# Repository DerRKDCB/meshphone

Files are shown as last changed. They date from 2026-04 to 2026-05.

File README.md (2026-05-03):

# Meshphone

A standalone dual-node Meshtastic/MeshCore device built into a Samsung Galaxy A5 form factor.

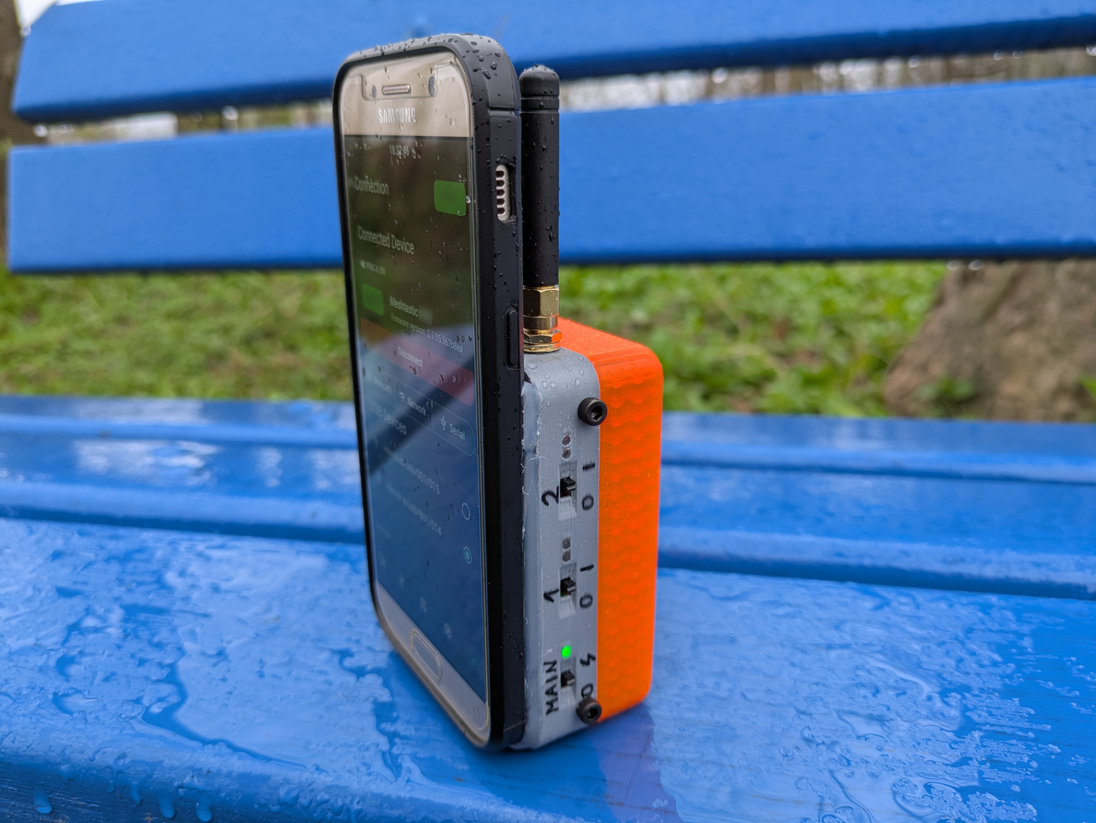
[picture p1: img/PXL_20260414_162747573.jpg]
Meshphone


## Overview

Meshphone is a custom dual-node Meshtastic device featuring:
- Two RAK4630 modules for simultaneous operation with different presets/protocols
- Integrated USB hub for clean connectivity
- 8000mAh 4P 18650 LiPo battery (~48h runtime)
- Samsung Galaxy A5 chassis (€20 eBay find)

## Why Build This?

Off-the-shelf standalone devices like the T-Deck lack the full feature set available in Meshtastic/MeshCore. By making it a dual-node device, I can run two different configurations simultaneously. The nodes connect through a USB hub IC - a cleaner solution than Bluetooth coupling with potential radio interference over short distances.

## Design

### Chassis
The Galaxy A5's internal battery was removed and replaced with external power from the PCB via cables. This allows complete disconnection via switch and increased battery capacity. The phone sits in a cheap TPU case, with 3D printed PLA housing for the nodes and batteries, secured with hot glue.

### Core Components

**RAK4630 Modules** - Chosen for:
- Low power consumption
- Minimal peripheral components
- Integrated USB

Reference designs: RAK4631 and RAK19003 modules.

> **Note:** The RAK USB port requires 5V on VBUS to initialize - learned this during integration and had to bodge it. Fixed in the PCB design.

**Status LEDs (7 total):**
- Charging indicator
- Fully charged indicator
- ON/3.3V OK
- 2x Status Node 1
- 2x Status Node 2

Light channels made from clear PETG filament - works awesome!

**Battery Management:**
- TP4056 + DW01 for charging and protection (classic LiPo charging circuit)
- USB-C charging port on bottom (power only, no data)

**USB Hub - CH334P:**
- First USB project for me
- Chosen for cost and simple reference schematic
- Upstream port centered on PCB
- Phone connects via right-angle USB-C cable
- Pluggable design allows connecting other devices for firmware updates, etc.
- Differential pair routing where possible - USB worked first try!

**3.3V Supply:** TI TPS62203DBVT low-power buck converter

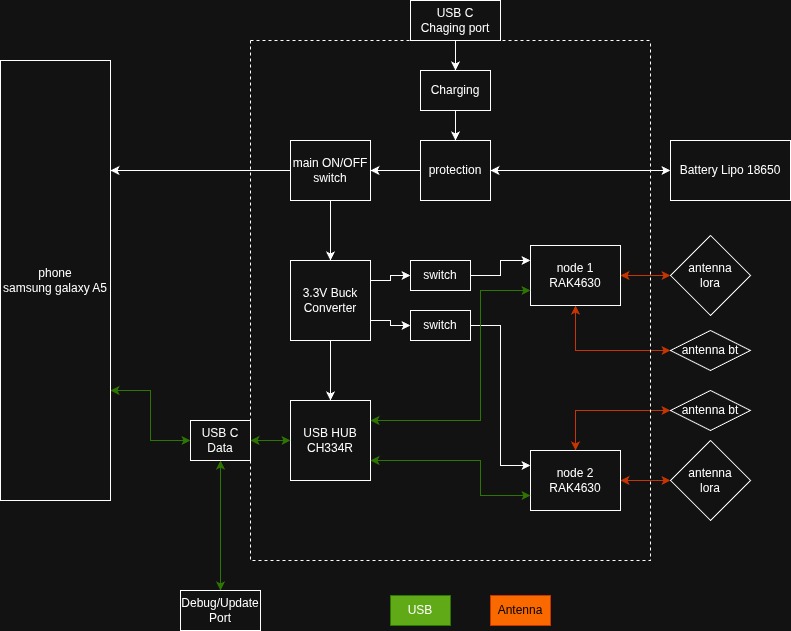
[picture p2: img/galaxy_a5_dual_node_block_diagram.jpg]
Block Diagram

[Schematic PDF](kicad/galaxy_A5_dual_node/galaxy_A5_dual_node.pdf)

### Fixes & Issues

**Bodged during build:**
- USB port didn't activate - forgot 5.1k resistors on CC1/CC2 (fixed in PCB)
- RAK VBUS 5V supply (fixed in PCB)
- Bootloader flash via SWD required for USB drive mode (double-click reset) - used [WisCore RAK4631 Bootloader](https://github.com/oltaco/WisCore_RAK4631_Bootloader)

**Remaining issue:**
When switching on either node, the hub disconnects and reconnects completely, making it impossible to differentiate which node is which USB device. Not sure why this happens, but it's manageable.

## Documentation

- [Component references and links](notes.md)
- [KiCad PCB files](kicad/galaxy_A5_dual_node/)
- [FreeCAD 3D models](freecad/)

## Final Thoughts

This project was an awesome learning experience and I love the result. For future versions I'd do some things differently - most likely keeping the battery in the phone and supplying the whole PCB from the phone's USB port.

## Images

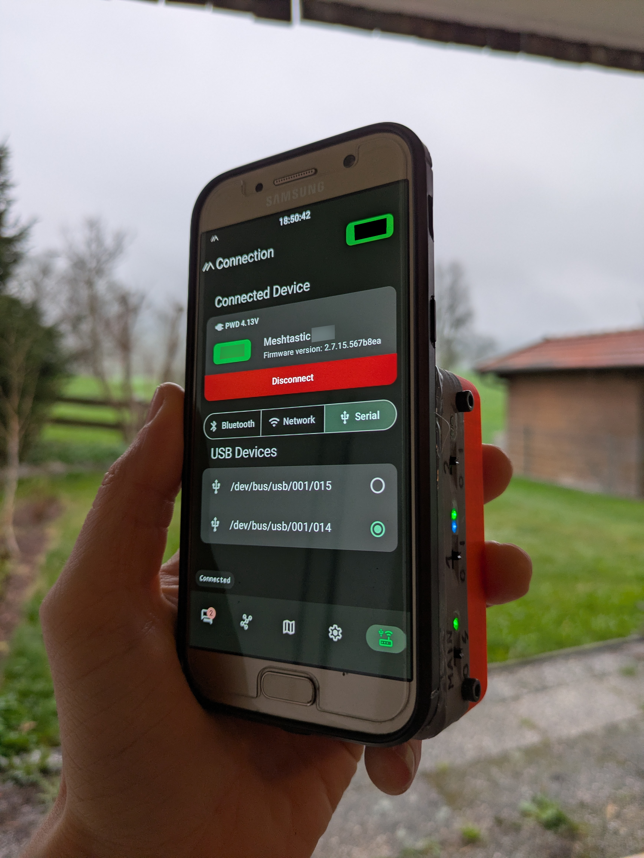
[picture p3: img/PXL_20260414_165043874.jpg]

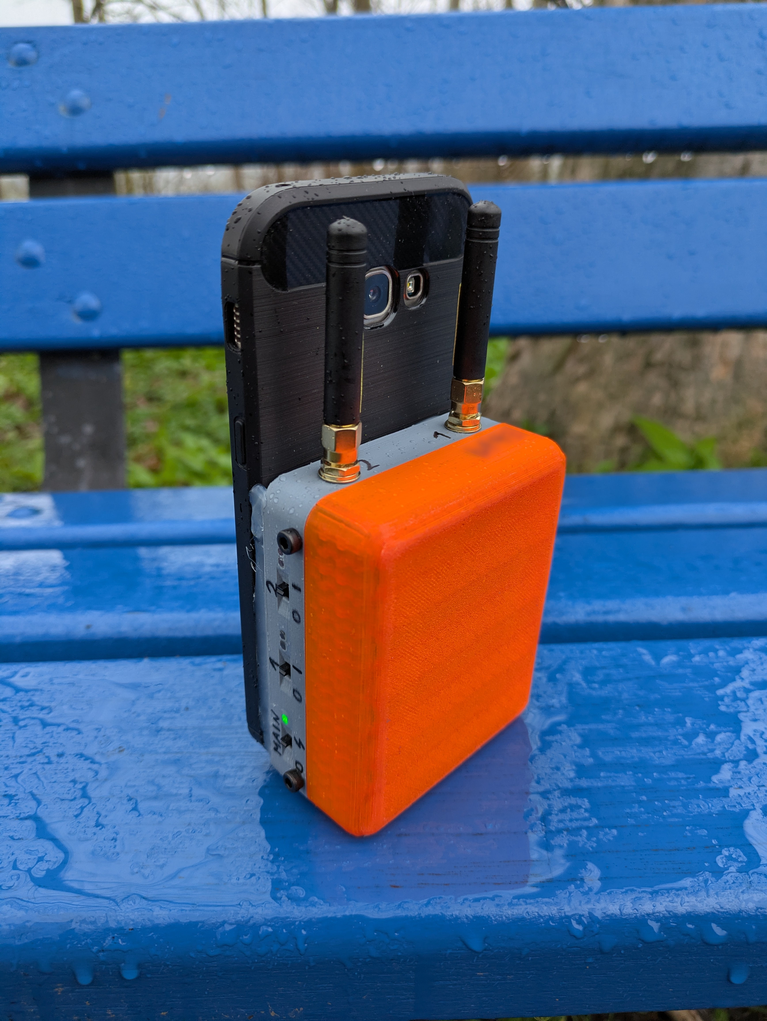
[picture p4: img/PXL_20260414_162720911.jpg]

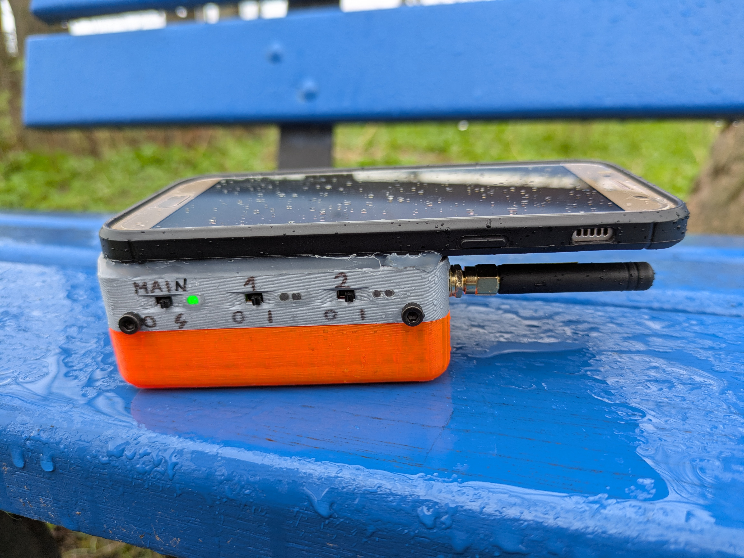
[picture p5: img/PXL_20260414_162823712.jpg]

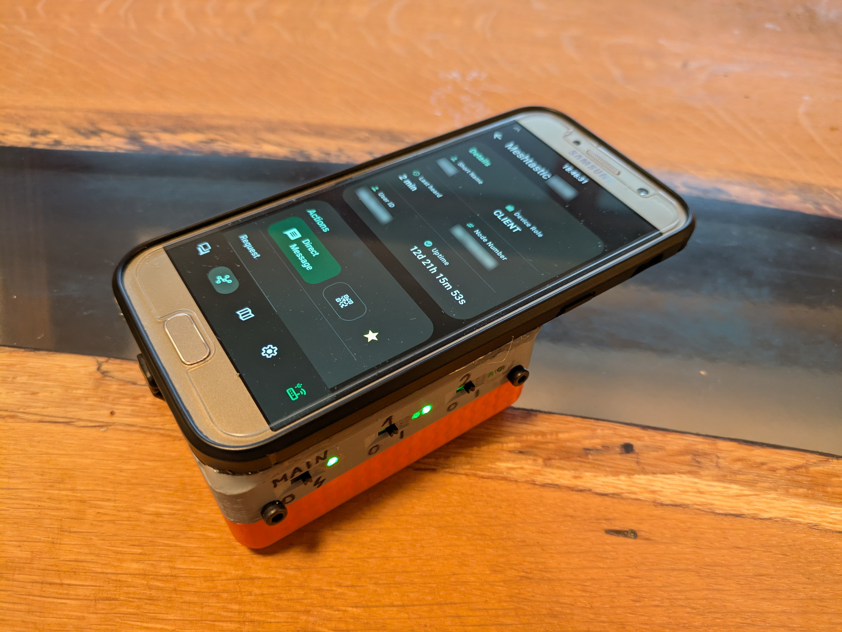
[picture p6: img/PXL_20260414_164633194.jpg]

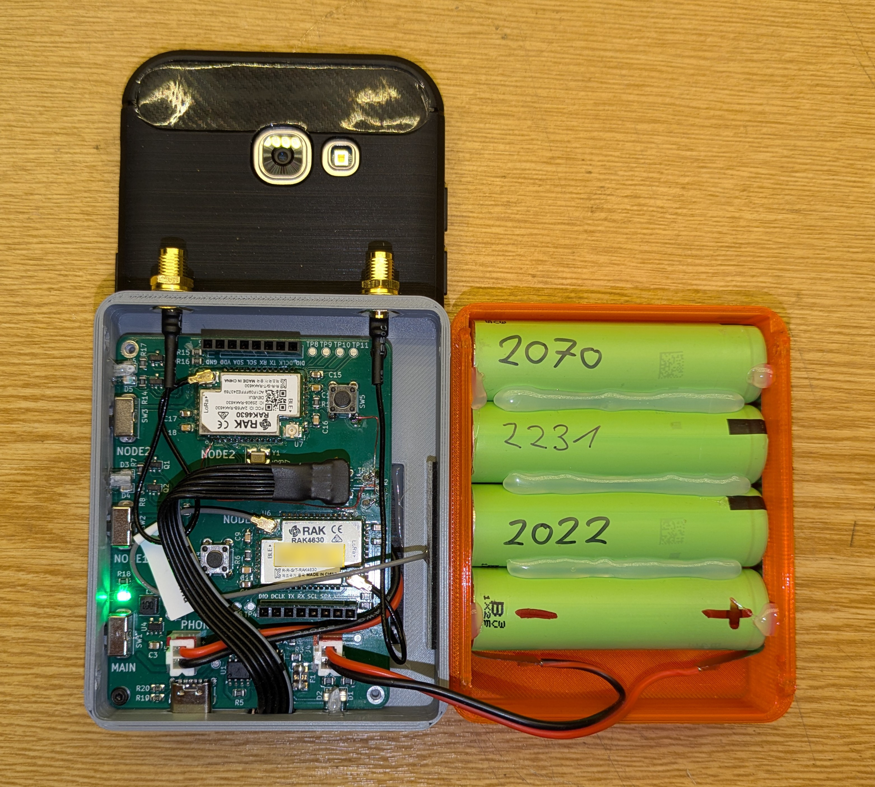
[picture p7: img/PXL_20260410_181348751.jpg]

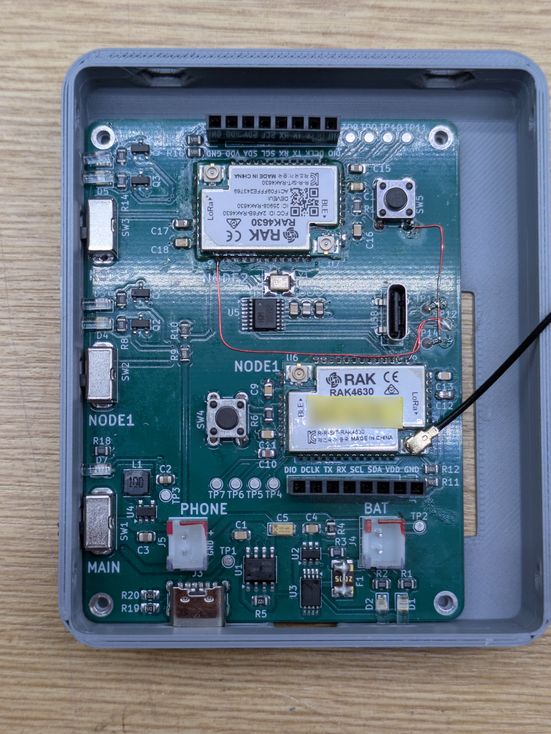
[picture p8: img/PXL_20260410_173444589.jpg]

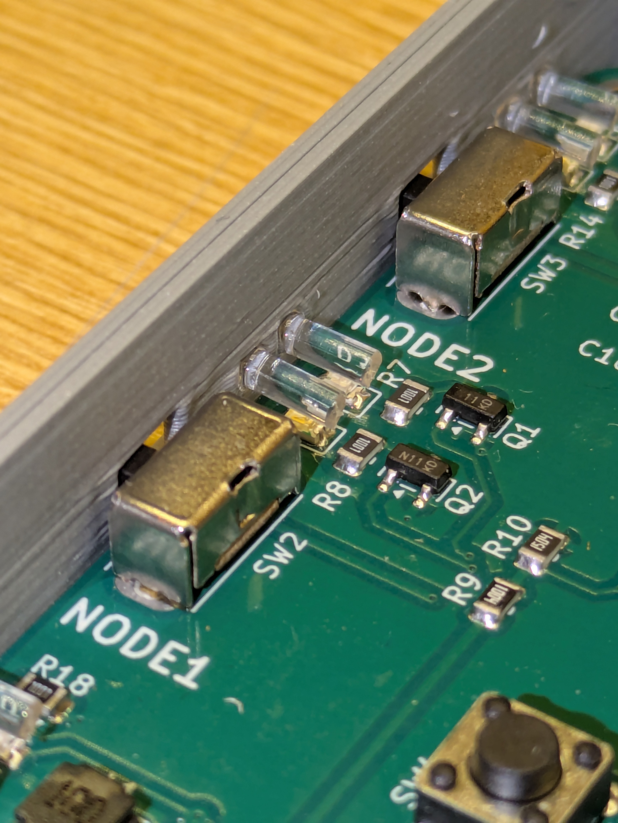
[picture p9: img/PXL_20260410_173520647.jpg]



by DerRKDCB

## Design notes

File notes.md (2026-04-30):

galaxy_a5_dual_node_block_diagram

# RAK4630

https://de.aliexpress.com/item/1005004148412772.html

https://docs.rakwireless.com/product-categories/wisduo/rak4630-module/datasheet/

minimal Hardware Setup
https://docs.rakwireless.com/product-categories/wisduo/rak4630-module/quickstart/#hardware-setup

# RAK4631

overview
https://docs.rakwireless.com/product-categories/wisblock/rak4631/overview/

datasheet
https://docs.rakwireless.com/product-categories/wisblock/rak4631/datasheet/

# RAK19003

https://docs.rakwireless.com/product-categories/wisblock/rak19003/datasheet/

TPS62840YBG

# USB Hub

CH334P

lcsc
https://www.lcsc.com/product-detail/C5373042.html?s_z=n_usb%2520hub%2520wch

datasheet
https://cdn-learn.adafruit.com/assets/assets/000/131/435/original/CH334DS1.PDF?1721660148

VDD33 and V5 can be supplied with 3.3V

differential pair tutorial 
https://www.pcbway.com/blog/PCB_Design_Tutorial/KiCad____How_to_make_differential_pair_traces.html

# LiPo

## Charging + Protection

Reference TP4056


datasheet https://datasheet.lcsc.com/lcsc/1809261820_TOPPOWER-Nanjing-Extension-Microelectronics-TP4056-42-ESOP8_C16581.pdf

R3
rprog

# 3.3V Buck

TI TPS62203DBVT
fixed 3.3V

lcsc
https://www.lcsc.com/product-detail/C2070733.html?s_z=n_TPS62203DBVT

datasheet
https://www.lcsc.com/datasheet/C2070733.pdf

# USB C connector

## Vertical Data
lcsc
C7450621
https://www.lcsc.com/product-detail/C7450621.html

# Switches
lcsc
https://www.lcsc.com/product-detail/C393937.html

footprint:
SW_Slide_SPDT_Angled_CK_OS102011MA1Q

# TODO

- OK power led 3.3V/VDD
- OK status leds RAK
- OK mounting holes
- OK testpoints- SDIO, RXTX Breakout
- OK reset button

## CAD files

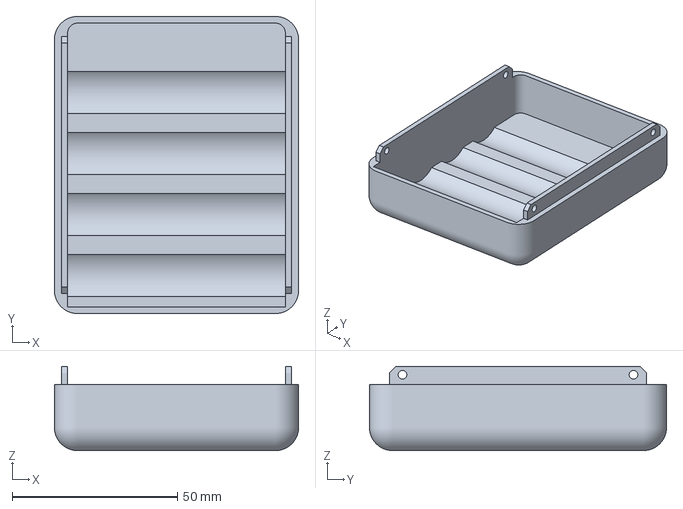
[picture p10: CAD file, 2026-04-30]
freecad/3mf/housing-battery_lid.3mf
74.0 x 90.0 x 25.5 mm

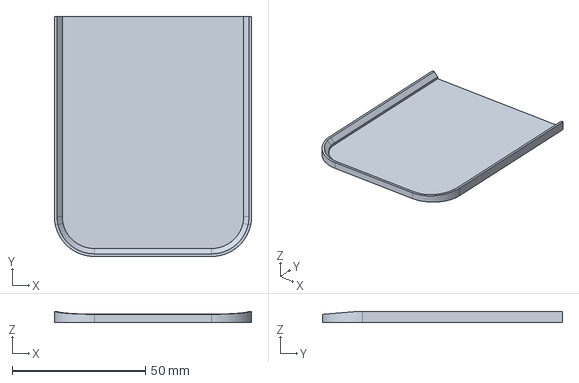
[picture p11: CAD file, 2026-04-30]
freecad/phone_case_size_test.FCStd
74.0 x 90.0 x 4.00 mm

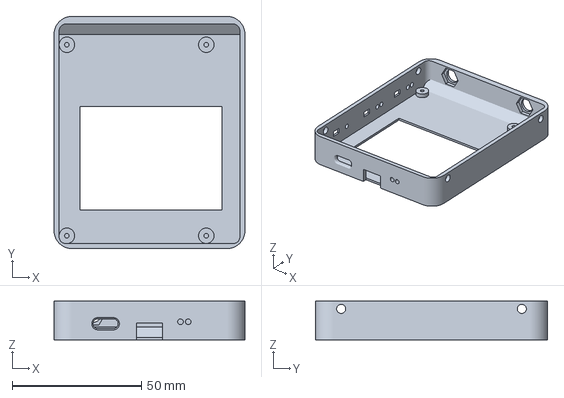
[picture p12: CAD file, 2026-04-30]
freecad/3mf/housing-pcb_housing.3mf
74.0 x 90.0 x 15.0 mm

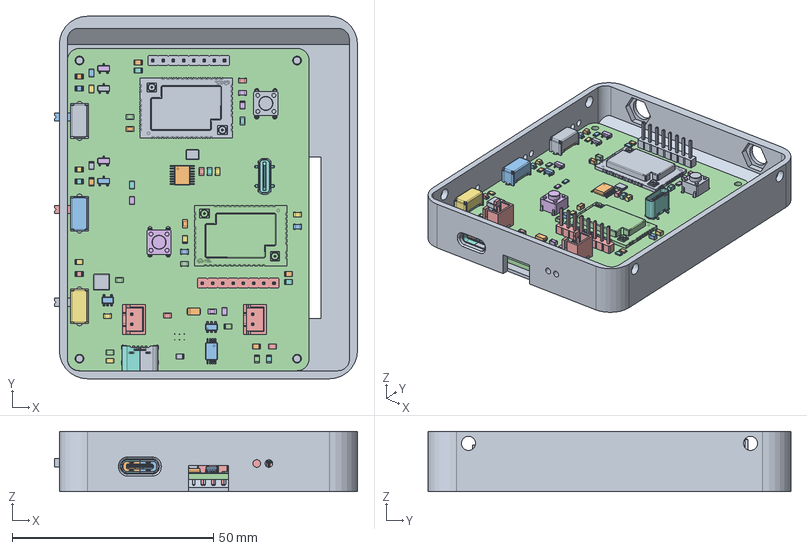
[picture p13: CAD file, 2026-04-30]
freecad/back_housing.FCStd
75.2 x 90.0 x 15.0 mm
LED_0805_2012Metric
C_0805_2012Metric
R_0805_2012Metric
LED_0805_2012Metric001
SOT-23
C_0805_2012Metric001
R_0805_2012Metric001
SW_Slide_SPDT_Angled_CK_OS102011MA1Q
SW_Slide_SPDT_Angled_CK_OS102011MA1Q001
SW_Slide_SPDT_Angled_CK_OS102011MA1Q002
SW_Slide_SPDT_Angled_CK_OS102011MA1Q003
SW_Slide_SPDT_Angled_CK_OS102011MA1Q004
SW_Slide_SPDT_Angled_CK_OS102011MA1Q005
SW_Slide_SPDT_Angled_CK_OS102011MA1Q007
SW_Slide_SPDT_Angled_CK_OS102011MA1Q008
SW_Slide_SPDT_Angled_CK_OS102011MA1Q009
SW_Slide_SPDT_Angled_CK_OS102011MA1Q010
SW_Slide_SPDT_Angled_CK_OS102011MA1Q011
SW_Slide_SPDT_Angled_CK_OS102011MA1Q012
C_0805_2012Metric002
C_0805_2012Metric003
R_0805_2012Metric002
C_0805_2012Metric004
L_APV_ANR4018
R_0805_2012Metric003
SOT-001
C_0805_2012Metric005
JST_XH_B2B-XH-A_1x02_P2.50mm_Vertical
SW_PUSH_6mm_H5mm
R_0805_2012Metric004
LED_0805_2012Metric002
PinHeader_1x08_P2.54mm_Vertical
R_0805_2012Metric005
SOT-23-5
R_0805_2012Metric006
R_0805_2012Metric007
R_0805_2012Metric008
R_0805_2012Metric009
R_0805_2012Metric010
R_0805_2012Metric011
USB_C_Receptacle_GCT_USB4125-xx-x_6P_TopMnt_Horizontal
USB_C_Receptacle_GCT_USB4125-xx-x_6P_TopMnt_Horizontal001
USB_C_Receptacle_GCT_USB4125-xx-x_6P_TopMnt_Horizontal002
USB_C_Receptacle_GCT_USB4125-xx-x_6P_TopMnt_Horizontal003
USB_C_Receptacle_GCT_USB4125-xx-x_6P_TopMnt_Horizontal004
USB_C_Receptacle_GCT_USB4125-xx-x_6P_TopMnt_Horizontal005
USB_C_Receptacle_GCT_USB4125-xx-x_6P_TopMnt_Horizontal006
USB_C_Receptacle_GCT_USB4125-xx-x_6P_TopMnt_Horizontal007
USB_C_Receptacle_GCT_USB4125-xx-x_6P_TopMnt_Horizontal008
USB_C_Receptacle_GCT_USB4125-xx-x_6P_TopMnt_Horizontal009
USB_C_Receptacle_GCT_USB4125-xx-x_6P_TopMnt_Horizontal010
USB_C_Receptacle_GCT_USB4125-xx-x_6P_TopMnt_Horizontal011
USB_C_Receptacle_GCT_USB4125-xx-x_6P_TopMnt_Horizontal012
USB_C_Receptacle_GCT_USB4125-xx-x_6P_TopMnt_Horizontal013
USB_C_Receptacle_GCT_USB4125-xx-x_6P_TopMnt_Horizontal014
USB_C_Receptacle_GCT_USB4125-xx-x_6P_TopMnt_Horizontal015
C_0805_2012Metric006
TSSOP-8_4.4x3mm_P0.65mm
COMM-SMD_44P-L23.0-W15.0-P1.20_RAK4630-8-SM-I
JST_XH_B2B-XH-A_1x02_P2.50mm_Vertical001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

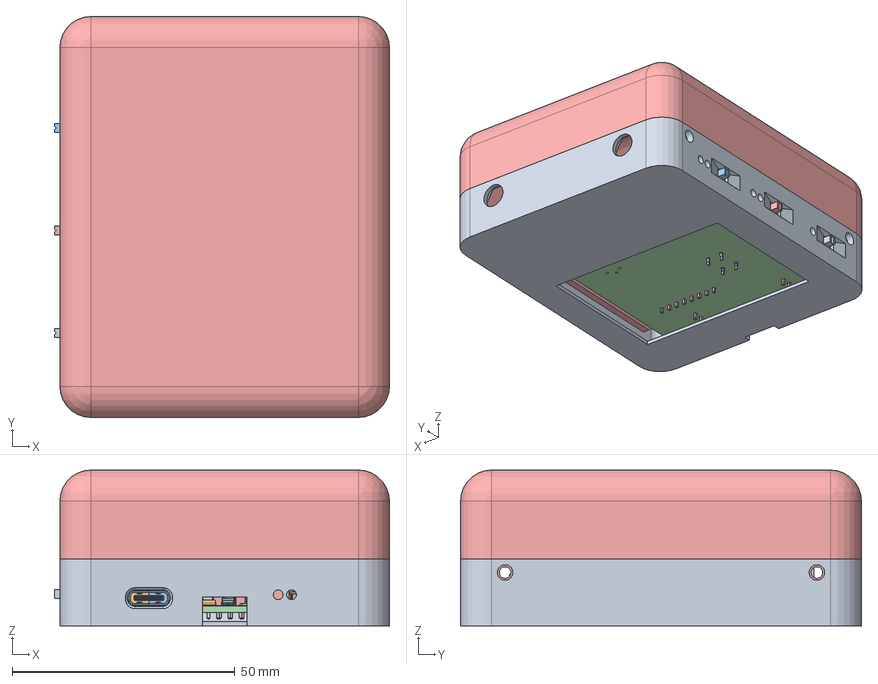
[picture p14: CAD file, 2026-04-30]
freecad/housing.FCStd
75.2 x 90.0 x 35.0 mm
pcb_housing
LED_0805_2012Metric
C_0805_2012Metric
R_0805_2012Metric
LED_0805_2012Metric001
SOT-23
C_0805_2012Metric001
R_0805_2012Metric001
SW_Slide_SPDT_Angled_CK_OS102011MA1Q
SW_Slide_SPDT_Angled_CK_OS102011MA1Q001
SW_Slide_SPDT_Angled_CK_OS102011MA1Q002
SW_Slide_SPDT_Angled_CK_OS102011MA1Q003
SW_Slide_SPDT_Angled_CK_OS102011MA1Q004
SW_Slide_SPDT_Angled_CK_OS102011MA1Q005
SW_Slide_SPDT_Angled_CK_OS102011MA1Q007
SW_Slide_SPDT_Angled_CK_OS102011MA1Q008
SW_Slide_SPDT_Angled_CK_OS102011MA1Q009
SW_Slide_SPDT_Angled_CK_OS102011MA1Q010
SW_Slide_SPDT_Angled_CK_OS102011MA1Q011
SW_Slide_SPDT_Angled_CK_OS102011MA1Q012
C_0805_2012Metric002
C_0805_2012Metric003
R_0805_2012Metric002
C_0805_2012Metric004
L_APV_ANR4018
R_0805_2012Metric003
SOT-001
C_0805_2012Metric005
JST_XH_B2B-XH-A_1x02_P2.50mm_Vertical
SW_PUSH_6mm_H5mm
R_0805_2012Metric004
LED_0805_2012Metric002
PinHeader_1x08_P2.54mm_Vertical
R_0805_2012Metric005
SOT-23-5
R_0805_2012Metric006
R_0805_2012Metric007
R_0805_2012Metric008
R_0805_2012Metric009
R_0805_2012Metric010
R_0805_2012Metric011
USB_C_Receptacle_GCT_USB4125-xx-x_6P_TopMnt_Horizontal
USB_C_Receptacle_GCT_USB4125-xx-x_6P_TopMnt_Horizontal001
USB_C_Receptacle_GCT_USB4125-xx-x_6P_TopMnt_Horizontal002
USB_C_Receptacle_GCT_USB4125-xx-x_6P_TopMnt_Horizontal003
USB_C_Receptacle_GCT_USB4125-xx-x_6P_TopMnt_Horizontal004
USB_C_Receptacle_GCT_USB4125-xx-x_6P_TopMnt_Horizontal005
USB_C_Receptacle_GCT_USB4125-xx-x_6P_TopMnt_Horizontal006
USB_C_Receptacle_GCT_USB4125-xx-x_6P_TopMnt_Horizontal007
USB_C_Receptacle_GCT_USB4125-xx-x_6P_TopMnt_Horizontal008
USB_C_Receptacle_GCT_USB4125-xx-x_6P_TopMnt_Horizontal009
USB_C_Receptacle_GCT_USB4125-xx-x_6P_TopMnt_Horizontal010
USB_C_Receptacle_GCT_USB4125-xx-x_6P_TopMnt_Horizontal011
USB_C_Receptacle_GCT_USB4125-xx-x_6P_TopMnt_Horizontal012
USB_C_Receptacle_GCT_USB4125-xx-x_6P_TopMnt_Horizontal013
USB_C_Receptacle_GCT_USB4125-xx-x_6P_TopMnt_Horizontal014
USB_C_Receptacle_GCT_USB4125-xx-x_6P_TopMnt_Horizontal015
C_0805_2012Metric006
TSSOP-8_4.4x3mm_P0.65mm
COMM-SMD_44P-L23.0-W15.0-P1.20_RAK4630-8-SM-I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

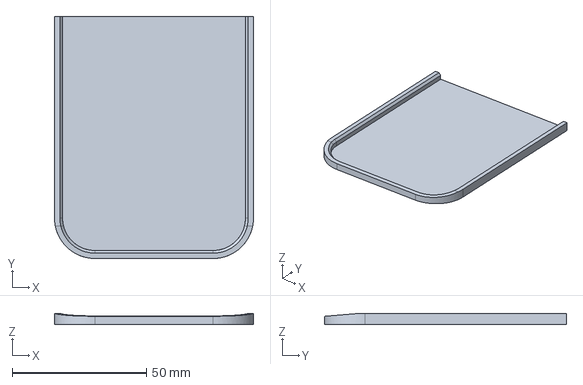
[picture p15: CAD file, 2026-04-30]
freecad/phone_case_size_test.sync-conflict-20260314-142446-KBQ5AQF.FCStd
74.0 x 90.0 x 4.00 mm

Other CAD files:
freecad/3mf/phone_case_size_test-Body.3mf
freecad/phone_case_size_test.sync-conflict-20260314-142535-KBQ5AQF.FCStd

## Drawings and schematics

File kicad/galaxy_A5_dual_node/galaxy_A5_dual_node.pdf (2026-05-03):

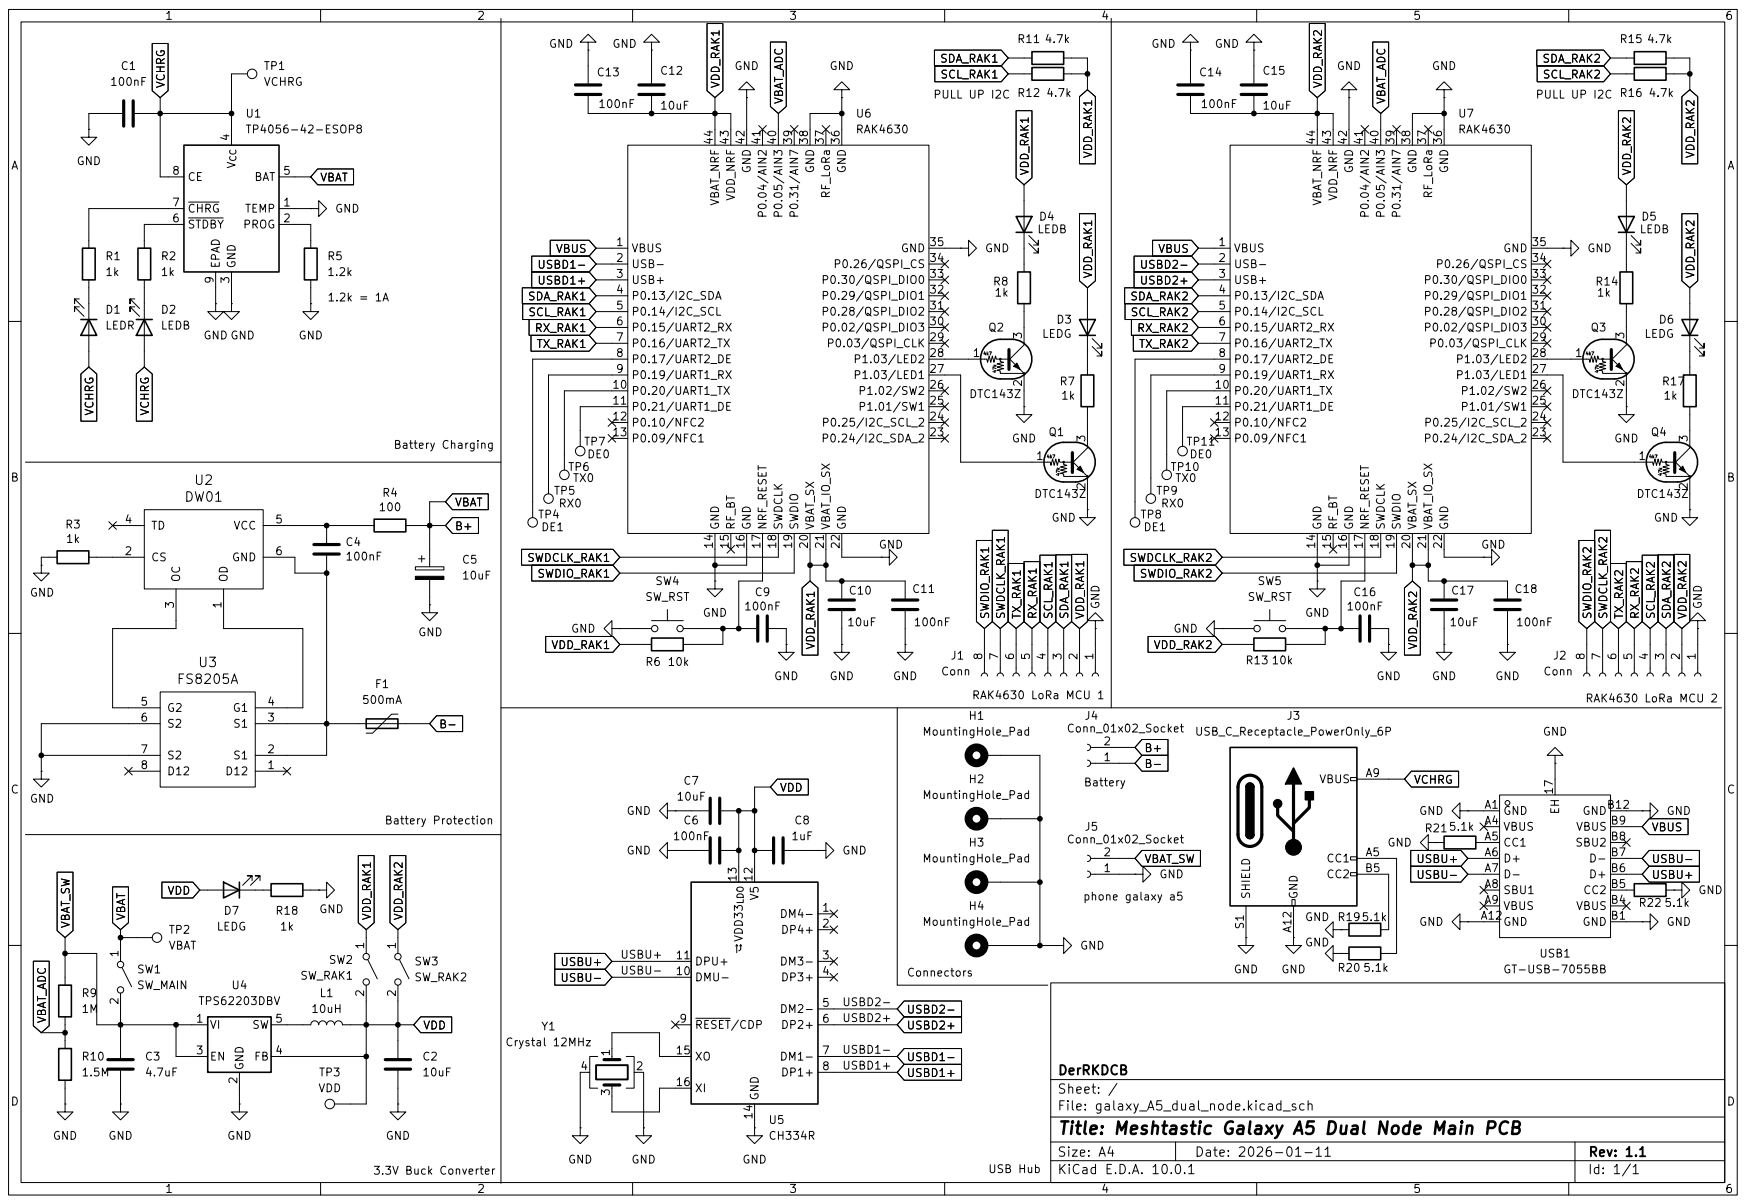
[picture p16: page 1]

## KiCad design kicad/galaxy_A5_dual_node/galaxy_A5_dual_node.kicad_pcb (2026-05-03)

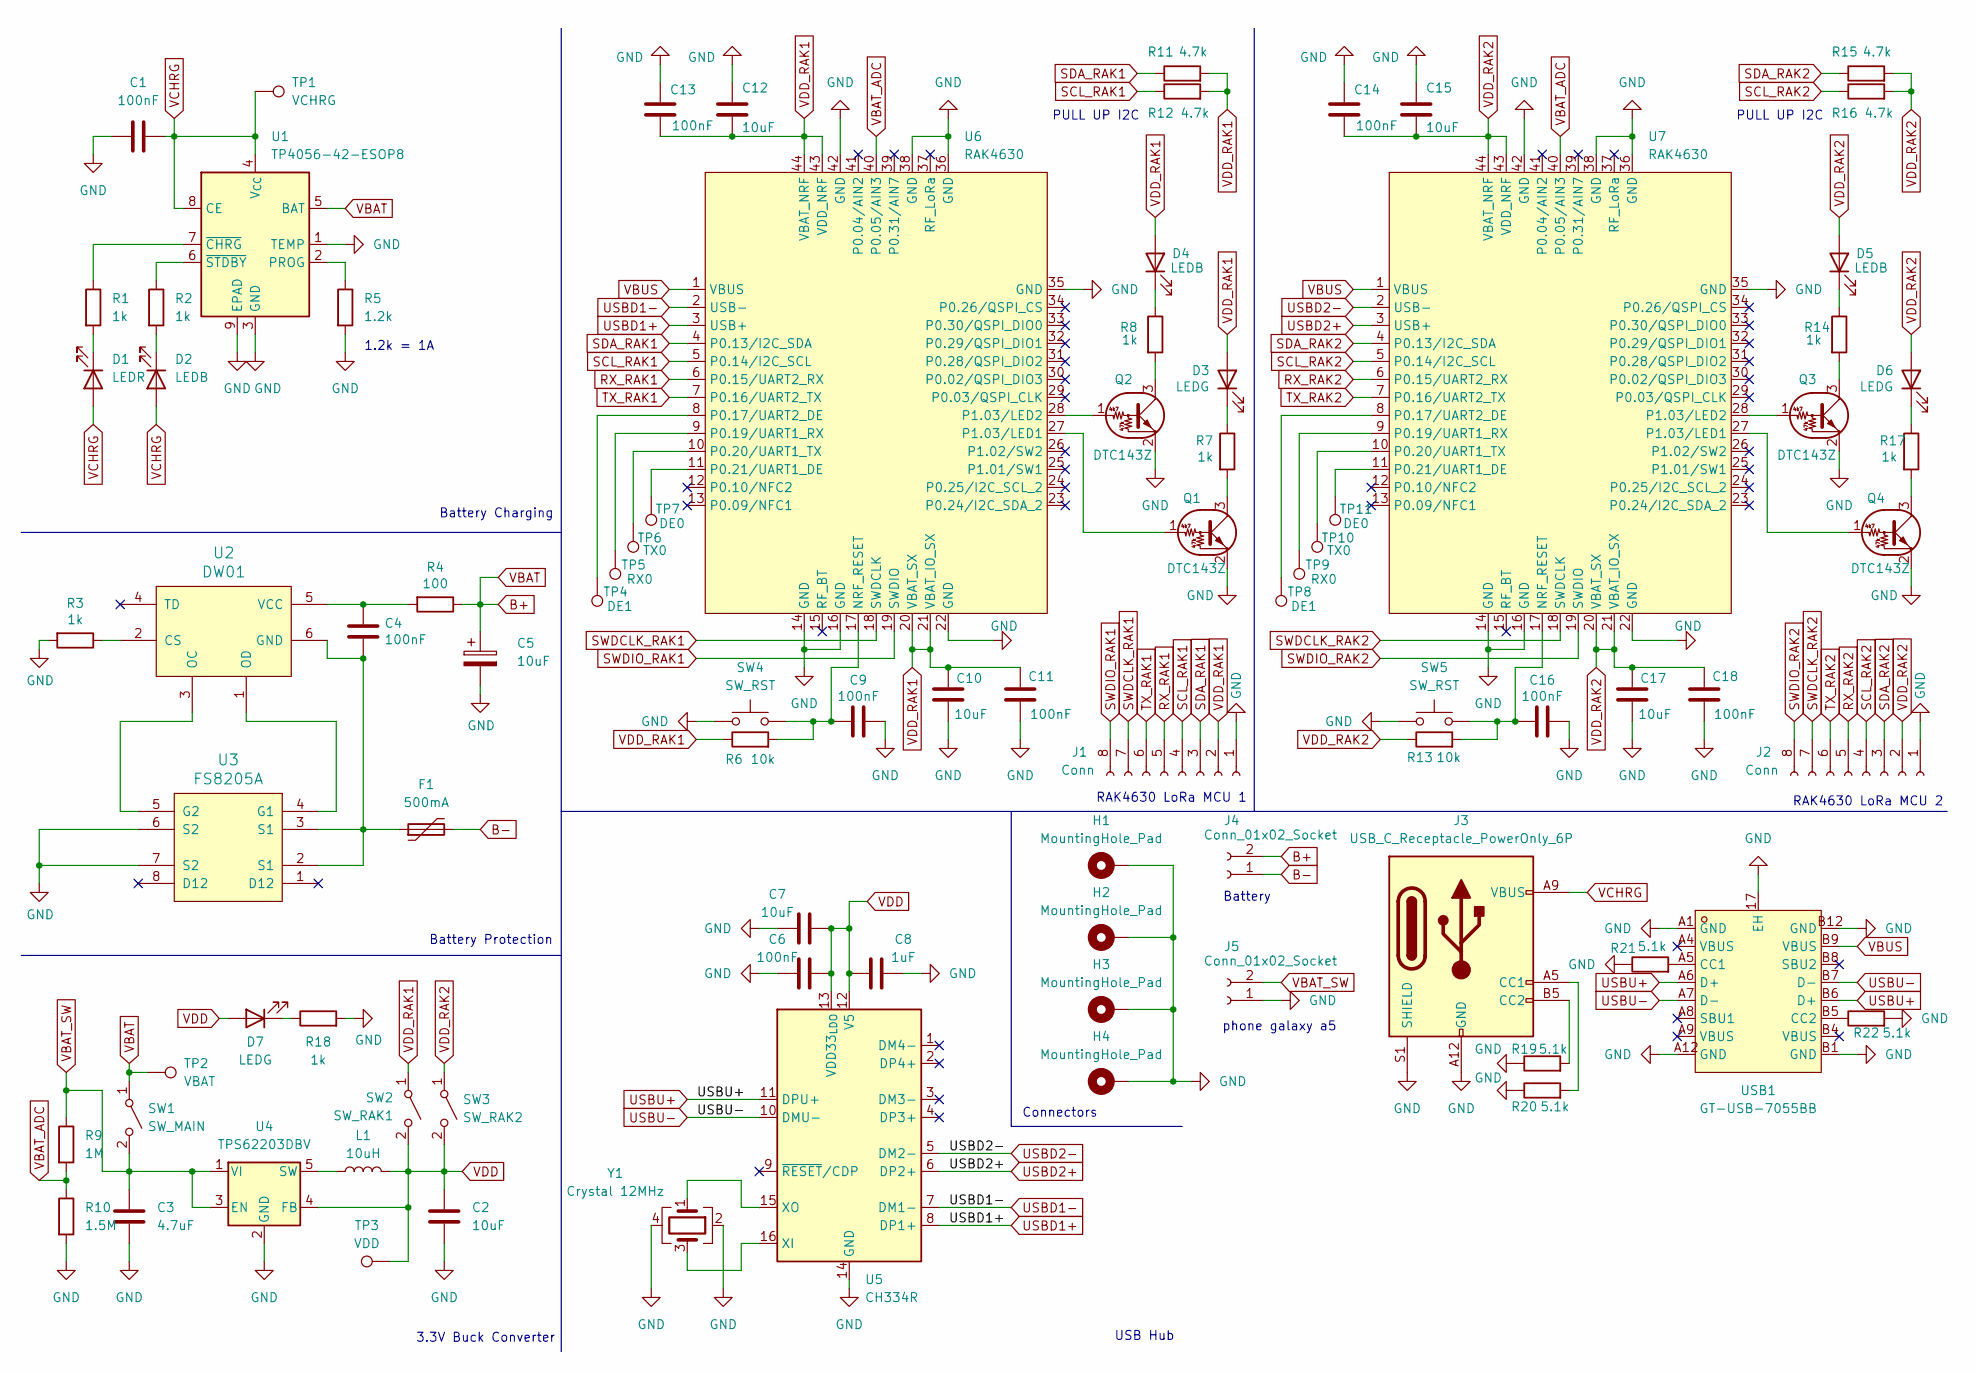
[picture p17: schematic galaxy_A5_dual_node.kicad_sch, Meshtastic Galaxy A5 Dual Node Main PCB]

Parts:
C1, C4, C6, C9, C11, C13, C14, C16, C18: 100nF; C_0805_2012Metric
C2, C7, C10, C12, C15, C17: 10uF; C_0805_2012Metric
C3: 4.7uF; C_0805_2012Metric
C5: 10uF; CP_EIA-3216-12_Kemet-S
C8: 1uF; C_0805_2012Metric
D1: LEDR; LED_0805_2012Metric
D2, D4, D5: LEDB; LED_0805_2012Metric
D3, D6, D7: LEDG; LED_0805_2012Metric
F1: 500mA; Fuse_1812_4532Metric_Pad1.30x3.40mm_HandSolder
H1, H2, H3, H4: MountingHole_Pad; MountingHole_2.2mm_M2_DIN965_Pad_TopBottom
J1, J2: Conn; PinHeader_1x08_P2.54mm_Vertical
J3: USB_C_Receptacle_PowerOnly_6P; USB_C_Receptacle_GCT_USB4125-xx-x_6P_TopMnt_Horizontal
J4, J5: Conn_01x02_Socket; JST_XH_B2B-XH-A_1x02_P2.50mm_Vertical
L1: 10uH; L_APV_ANR4018
Q1, Q2, Q3, Q4: DTC143Z; SOT-23
R1, R2, R3, R7, R8, R14, R17, R18: 1k; R_0805_2012Metric
R4: 100; R_0805_2012Metric
R5: 1.2k; R_0805_2012Metric
R6, R13: 10k; R_0805_2012Metric
R9: 1M; R_0805_2012Metric
R10: 1.5M; R_0805_2012Metric
R11, R12, R15, R16: 4.7k; R_0805_2012Metric
R19, R20, R21, R22: 5.1k; R_0805_2012Metric
SW1: SW_MAIN; SW_Slide_SPDT_Angled_CK_OS102011MA1Q
SW2: SW_RAK1; SW_Slide_SPDT_Angled_CK_OS102011MA1Q
SW3: SW_RAK2; SW_Slide_SPDT_Angled_CK_OS102011MA1Q
SW4, SW5: SW_RST; SW_PUSH_6mm_H5mm
TP1: VCHRG; TestPoint_Pad_D1.5mm
TP2: VBAT; TestPoint_Pad_D1.5mm
TP3: VDD; TestPoint_Pad_D1.5mm
TP4, TP8: DE1; TestPoint_Pad_D1.5mm
TP5, TP9: RX0; TestPoint_Pad_D1.5mm
TP6, TP10: TX0; TestPoint_Pad_D1.5mm
TP7, TP11: DE0; TestPoint_Pad_D1.5mm
U1: TP4056-42-ESOP8; SOIC-8-1EP_3.9x4.9mm_P1.27mm_EP2.41x3.3mm_ThermalVias
U2: DW01; SOT-23-6
U3: FS8205A; TSSOP-8_4.4x3mm_P0.65mm
U4: TPS62203DBV; SOT-23-5
U5: CH334R; QSOP-16_3.9x4.9mm_P0.635mm
U6, U7: RAK4630; rak4630
USB1: GT-USB-7055BB; USB-C-TH_GT-USB-7055BB; LCSC Part C7450621
Y1: Crystal 12MHz; Crystal_SMD_3225-4Pin_3.2x2.5mm_HandSoldering

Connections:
B+: C5.1, J4.2, R4.1, SW1.1 (A), TP2.1 (1_1), U1.5 (BAT)
B-: F1.2, J4.1
GND: C1.1, C2.2, C3.2, C5.2, C6.1, C7.1, C8.2, C9.2, C10.2, C11.2, C12.1, C13.1, C14.1, C15.1, C16.2, C17.2, C18.2, H1.1 (1_1), H2.1 (1_1), H3.1 (1_1), H4.1 (1_1), J1.1, J2.1, J3.A12 (GND), J3.B12 (GND), J3.S1 (SHIELD), J5.1, Q1.2 (E), Q2.2 (E), Q3.2 (E), Q4.2 (E), R3.2, R5.2, R10.2, R18.2, R19.1, R20.1, R21.1, R22.2, SW4.1, SW5.1, U1.1 (TEMP), U1.3 (GND), U1.9 (EPAD), U3.6 (S2), U3.7 (S2), U4.2 (GND), U5.14 (GND), U6.14 (GND), U6.16 (GND), U6.22 (GND), U6.35 (GND), U6.36 (GND), U6.38 (GND), U6.42 (GND), U7.14 (GND), U7.16 (GND), U7.22 (GND), U7.35 (GND), U7.36 (GND), U7.38 (GND), U7.42 (GND), USB1.17 (EH), USB1.A1 (GND), USB1.A12 (GND), USB1.B1 (GND), USB1.B12 (GND), Y1.2, Y1.4
unnamed: D1.1 (K), R1.2
unnamed: D2.1 (K), R2.2
unnamed: D3.1 (K), R7.1
unnamed: D4.1 (K), R8.1
unnamed: D5.1 (K), R14.1
unnamed: D6.1 (K), R17.1
unnamed: D7.1 (K), R18.1
unnamed: J3.A5 (CC1), R20.2
unnamed: J3.B5 (CC2), R19.2
unnamed: Q1.1 (B), U6.27 (P1.03/LED1)
unnamed: Q1.3 (C), R7.2
unnamed: Q2.1 (B), U6.28 (P1.03/LED2)
unnamed: Q2.3 (C), R8.2
unnamed: Q3.1 (B), U7.28 (P1.03/LED2)
unnamed: Q3.3 (C), R14.2
unnamed: Q4.1 (B), U7.27 (P1.03/LED1)
unnamed: Q4.3 (C), R17.2
unnamed: R5.1, U1.2 (PROG)
unnamed: R1.1, U1.7 (~CHRG)
unnamed: R2.1, U1.6 (~STDBY)
unnamed: R3.1, U2.2 (CS)
unnamed: C4.2, F1.1, U2.6 (GND), U3.2 (S1), U3.3 (S1)
unnamed: U2.3 (OC), U3.5 (G2)
unnamed: U2.1 (OD), U3.4 (G1)
unnamed: C4.1, R4.2, U2.5 (VCC)
unnamed: L1.1, U4.5 (SW)
unnamed: U5.16 (XI), Y1.3
unnamed: U5.15 (XO), Y1.1
unnamed: C9.1, R6.2, SW4.2, U6.17 (NRF_RESET)
unnamed: TP4.1 (1_1), U6.8 (P0.17/UART2_DE)
unnamed: TP5.1 (1_1), U6.9 (P0.19/UART1_RX)
unnamed: TP6.1 (1_1), U6.10 (P0.20/UART1_TX)
unnamed: TP7.1 (1_1), U6.11 (P0.21/UART1_DE)
unnamed: C16.1, R13.2, SW5.2, U7.17 (NRF_RESET)
unnamed: TP8.1 (1_1), U7.8 (P0.17/UART2_DE)
unnamed: TP9.1 (1_1), U7.9 (P0.19/UART1_RX)
unnamed: TP10.1 (1_1), U7.10 (P0.20/UART1_TX)
unnamed: TP11.1 (1_1), U7.11 (P0.21/UART1_DE)
unnamed: R21.2, USB1.A5 (CC1)
unnamed: R22.1, USB1.B5 (CC2)
RX_RAK1: J1.5, U6.6 (P0.15/UART2_RX)
RX_RAK2: J2.5, U7.6 (P0.15/UART2_RX)
SCL_RAK1: J1.4, R12.1, U6.5 (P0.14/I2C_SCL)
SCL_RAK2: J2.4, R16.1, U7.5 (P0.14/I2C_SCL)
SDA_RAK1: J1.3, R11.1, U6.4 (P0.13/I2C_SDA)
SDA_RAK2: J2.3, R15.1, U7.4 (P0.13/I2C_SDA)
SWDCLK_RAK1: J1.7, U6.18 (SWDCLK)
SWDCLK_RAK2: J2.7, U7.18 (SWDCLK)
SWDIO_RAK1: J1.8, U6.19 (SWDIO)
SWDIO_RAK2: J2.8, U7.19 (SWDIO)
TX_RAK1: J1.6, U6.7 (P0.16/UART2_TX)
TX_RAK2: J2.6, U7.7 (P0.16/UART2_TX)
USBD1+: U5.8 (DP1+), U6.3 (USB+)
USBD1-: U5.7 (DM1-), U6.2 (USB-)
USBD2+: U5.6 (DP2+), U7.3 (USB+)
USBD2-: U5.5 (DM2-), U7.2 (USB-)
USBU+: U5.11 (DPU+), USB1.A6 (D+), USB1.B6 (D+)
USBU-: U5.10 (DMU-), USB1.A7 (D-), USB1.B7 (D-)
VBAT_ADC: R9.2, R10.1, U6.40 (P0.05/AIN3), U7.40 (P0.05/AIN3)
VBAT_SW: C3.1, J5.2, R9.1, SW1.2 (B), U4.1 (VI), U4.3 (EN)
VBUS: U6.1 (VBUS), U7.1 (VBUS), USB1.B9 (VBUS)
VCHRG: C1.2, D1.2 (A), D2.2 (A), J3.A9 (VBUS), J3.B9 (VBUS), TP1.1 (1_1), U1.4 (V_{CC}), U1.8 (CE)
VDD: C2.1, C6.2, C7.2, C8.1, D7.2 (A), L1.2, SW2.2 (B), SW3.2 (B), TP3.1 (1_1), U4.4 (FB), U5.12 (V5), U5.13 (VDD33_{LDO})
VDD_RAK1: C10.1, C11.1, C12.2, C13.2, D3.2 (A), D4.2 (A), J1.2, R6.1, R11.2, R12.2, SW2.1 (A), U6.20 (VBAT_SX), U6.21 (VBAT_IO_SX), U6.43 (VDD_NRF), U6.44 (VBAT_NRF)
VDD_RAK2: C14.2, C15.2, C17.1, C18.1, D5.2 (A), D6.2 (A), J2.2, R13.1, R15.2, R16.2, SW3.1 (A), U7.20 (VBAT_SX), U7.21 (VBAT_IO_SX), U7.43 (VDD_NRF), U7.44 (VBAT_NRF)

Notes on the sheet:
PULL UP I2C
phone galaxy a5
RAK4630 LoRa MCU 2
Battery Protection
3.3V Buck Converter
Battery Charging
Connectors
USB Hub
Battery
1.2k = 1A
RAK4630 LoRa MCU 1

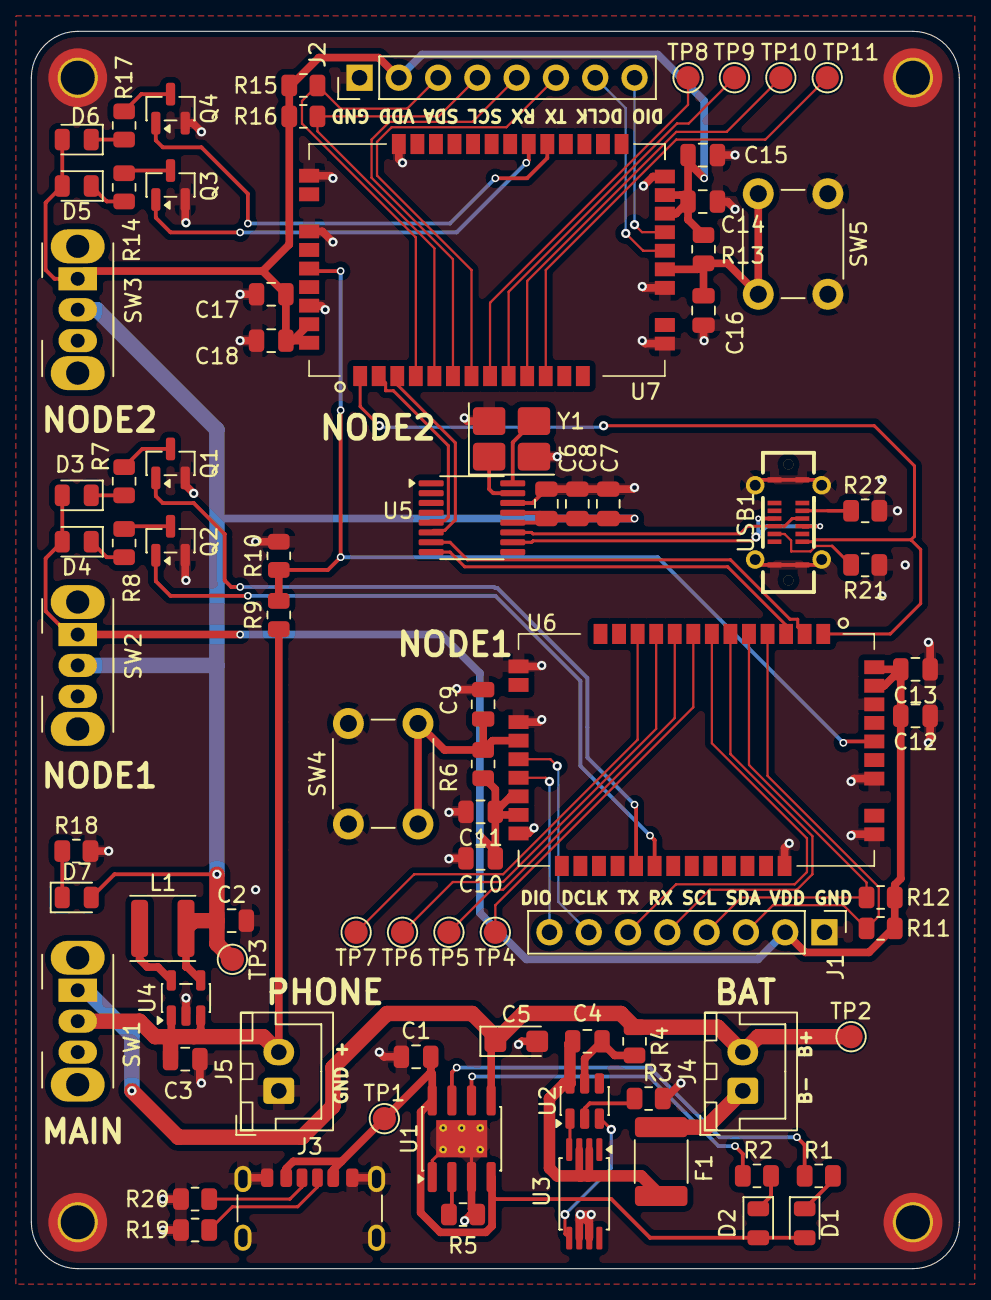
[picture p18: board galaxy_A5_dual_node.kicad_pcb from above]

Board: 2 copper layers, 60.0 x 80.0 mm, 87 parts (0 on the bottom side), 68 nets.

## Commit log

2026-04-30 cleanup freecad
    [back_housing-Body.3mf]
2026-04-30 fixed USB CC, VBUS RAK
    [galaxy_A5_dual_node-B_Cu.gbr, galaxy_A5_dual_node-B_Mask.gbr, galaxy_A5_dual_node-B_Paste.gbr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]
2026-04-30 kicad history gitignore
2026-05-03 update pcb version number
    [galaxy_A5_dual_node-B_Cu.gbr, galaxy_A5_dual_node-B_Mask.gbr, galaxy_A5_dual_node-B_Paste.gbr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]
